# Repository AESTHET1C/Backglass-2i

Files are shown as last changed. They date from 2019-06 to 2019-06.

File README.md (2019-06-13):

# Backglass 2 Integrated Pinball Controller Board

This is the "integrated" version of the [Backglass 2 Pinball Controller Board](https://github.com/AESTHET1C/Backglass-2). The I/O has been changed from wire receptacles to a ribbon cable, and the ordering has changed to better suit wire management.

---

An Arduino Uno-compatible unified control board tailored to the Eli Whitney Museum 2019 summer pinball project.

The board contains the following hardware:

* Microchip ATmega8U2/16U2 (serial communication and code upload)
* Microchip ATmega328P (user code)
* Microchip ATmega48PB (audio/visual coprocessing)
* 4-character 7 segment display
* 2 analogue inputs (for reflectance sensors)
* 5 digital inputs (with integrated pull-ups)
* 3 current-limited LED outputs
* 1 PWM-controlled motor output
* 1 speaker output
* Micro USB interface
* 2.7 - 6.5 volt power input

All features of the board, with the exception of the motor, can be powered via USB.

-----

A user-oriented code library can be found here: <https://github.com/AESTHET1C/Backglass-2-Library/>

The coprocessor firmware can be found here: <https://github.com/AESTHET1C/Backglass-2-Firmware/>

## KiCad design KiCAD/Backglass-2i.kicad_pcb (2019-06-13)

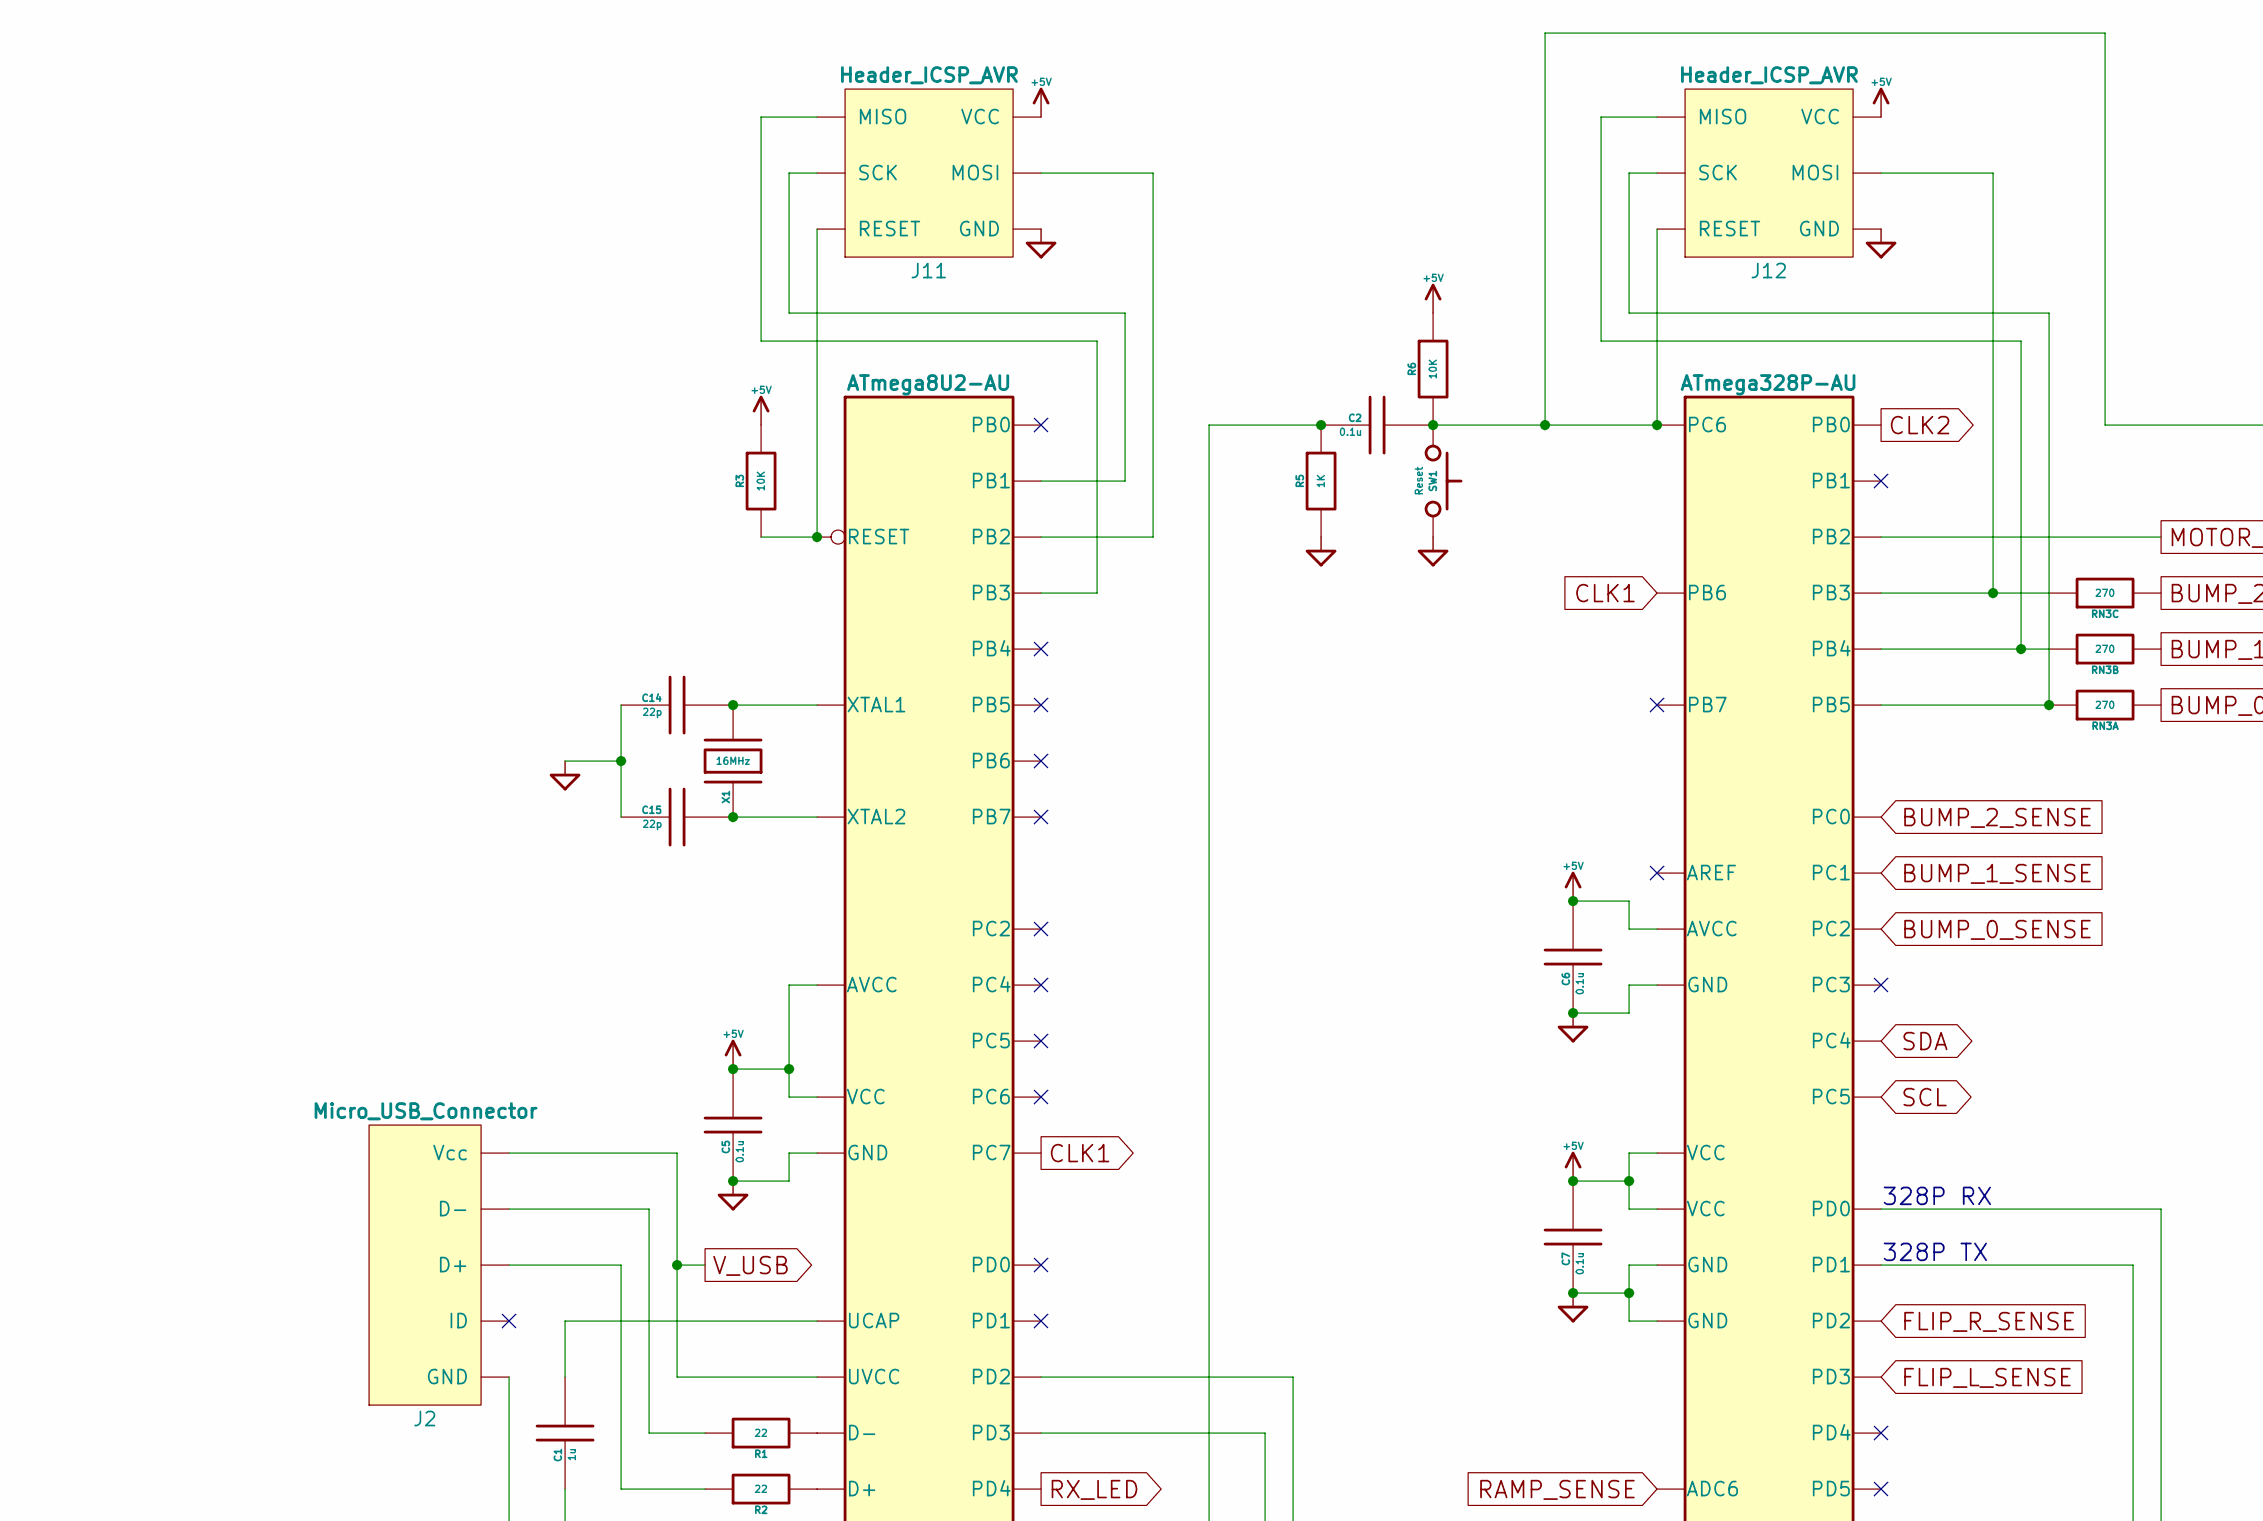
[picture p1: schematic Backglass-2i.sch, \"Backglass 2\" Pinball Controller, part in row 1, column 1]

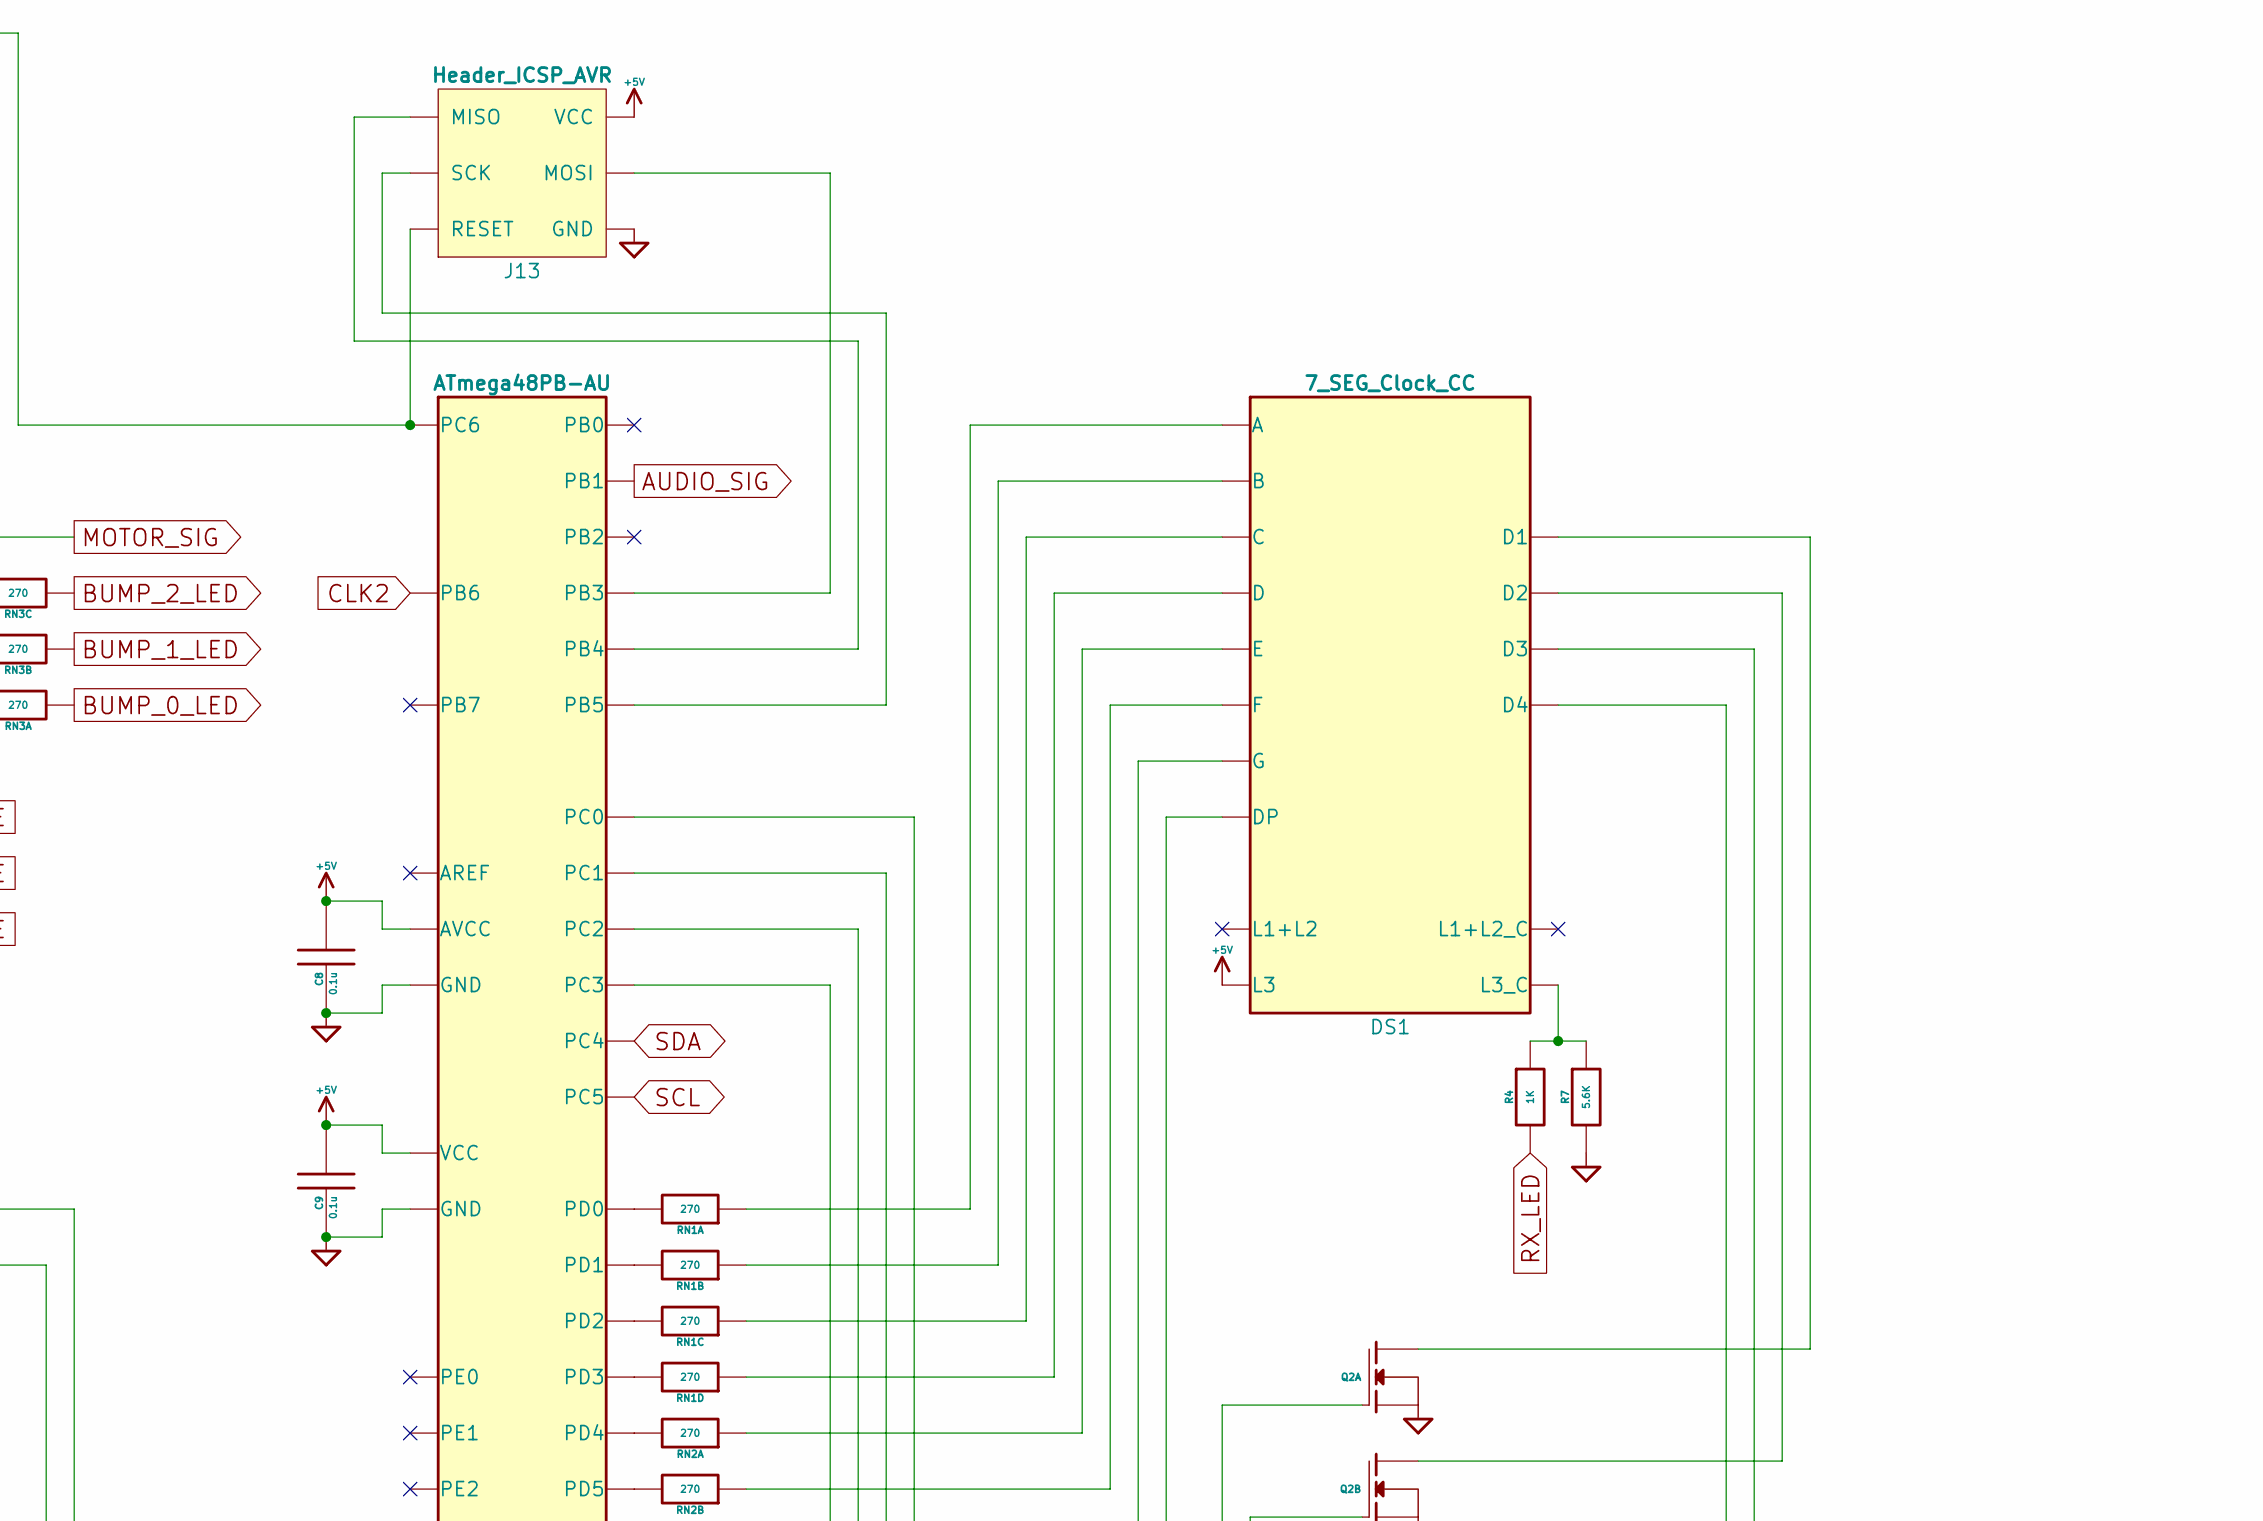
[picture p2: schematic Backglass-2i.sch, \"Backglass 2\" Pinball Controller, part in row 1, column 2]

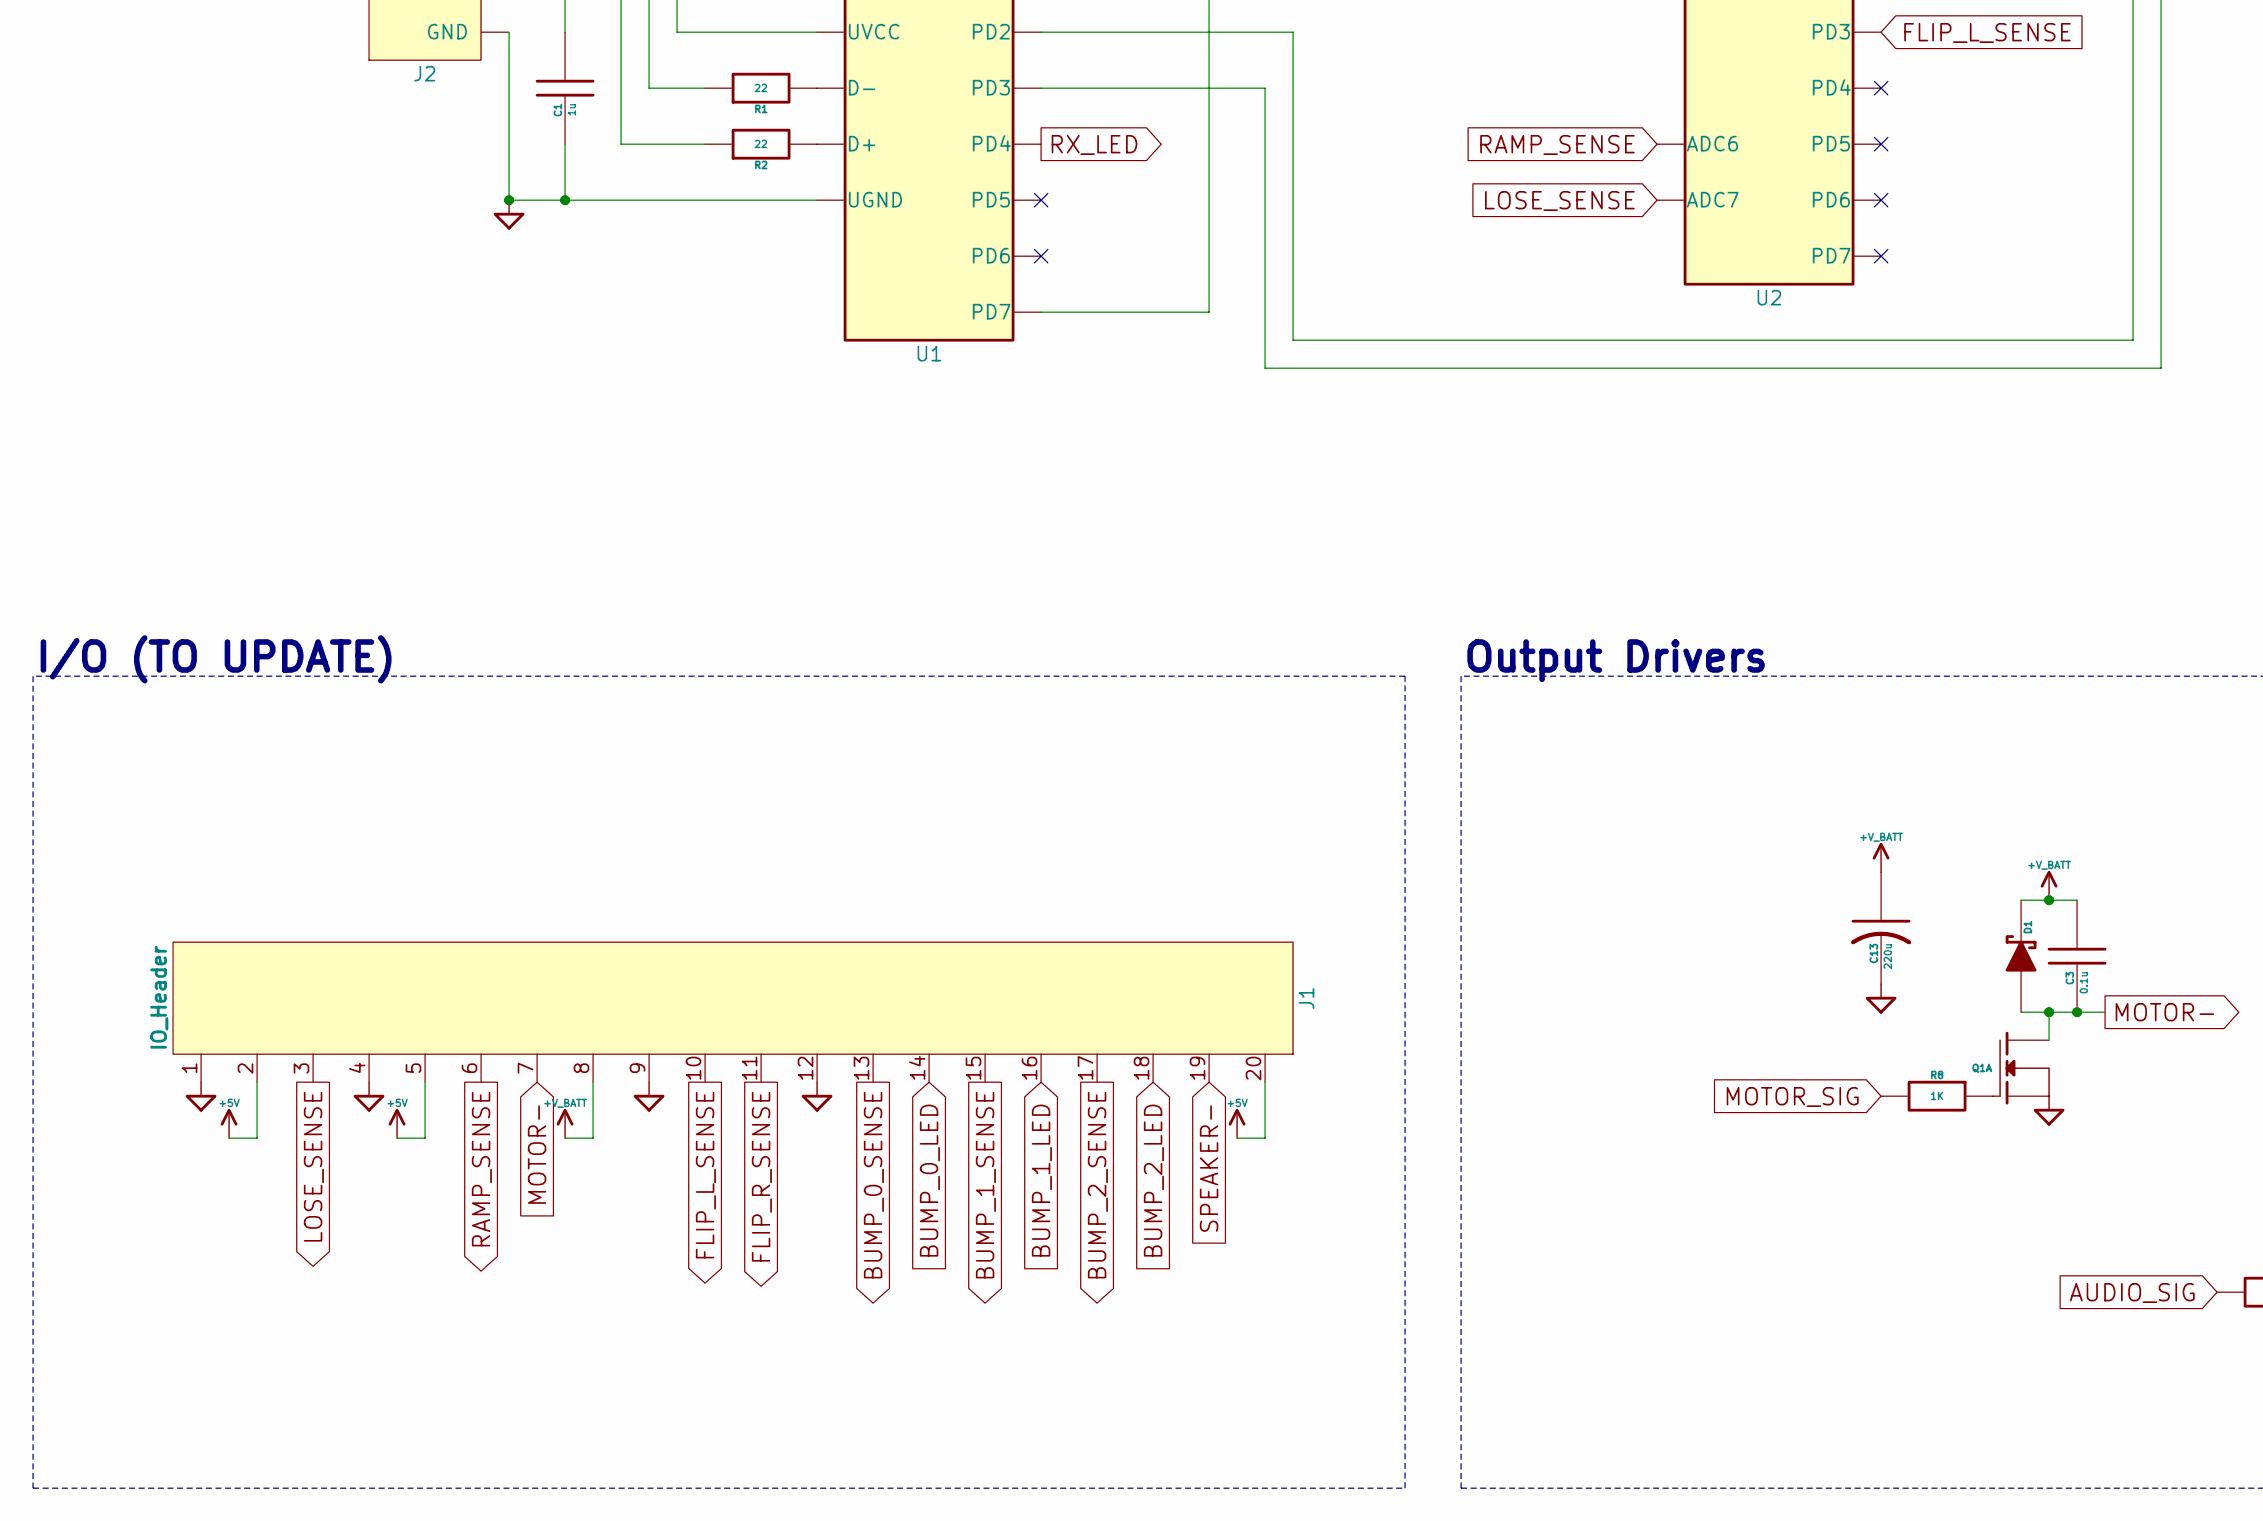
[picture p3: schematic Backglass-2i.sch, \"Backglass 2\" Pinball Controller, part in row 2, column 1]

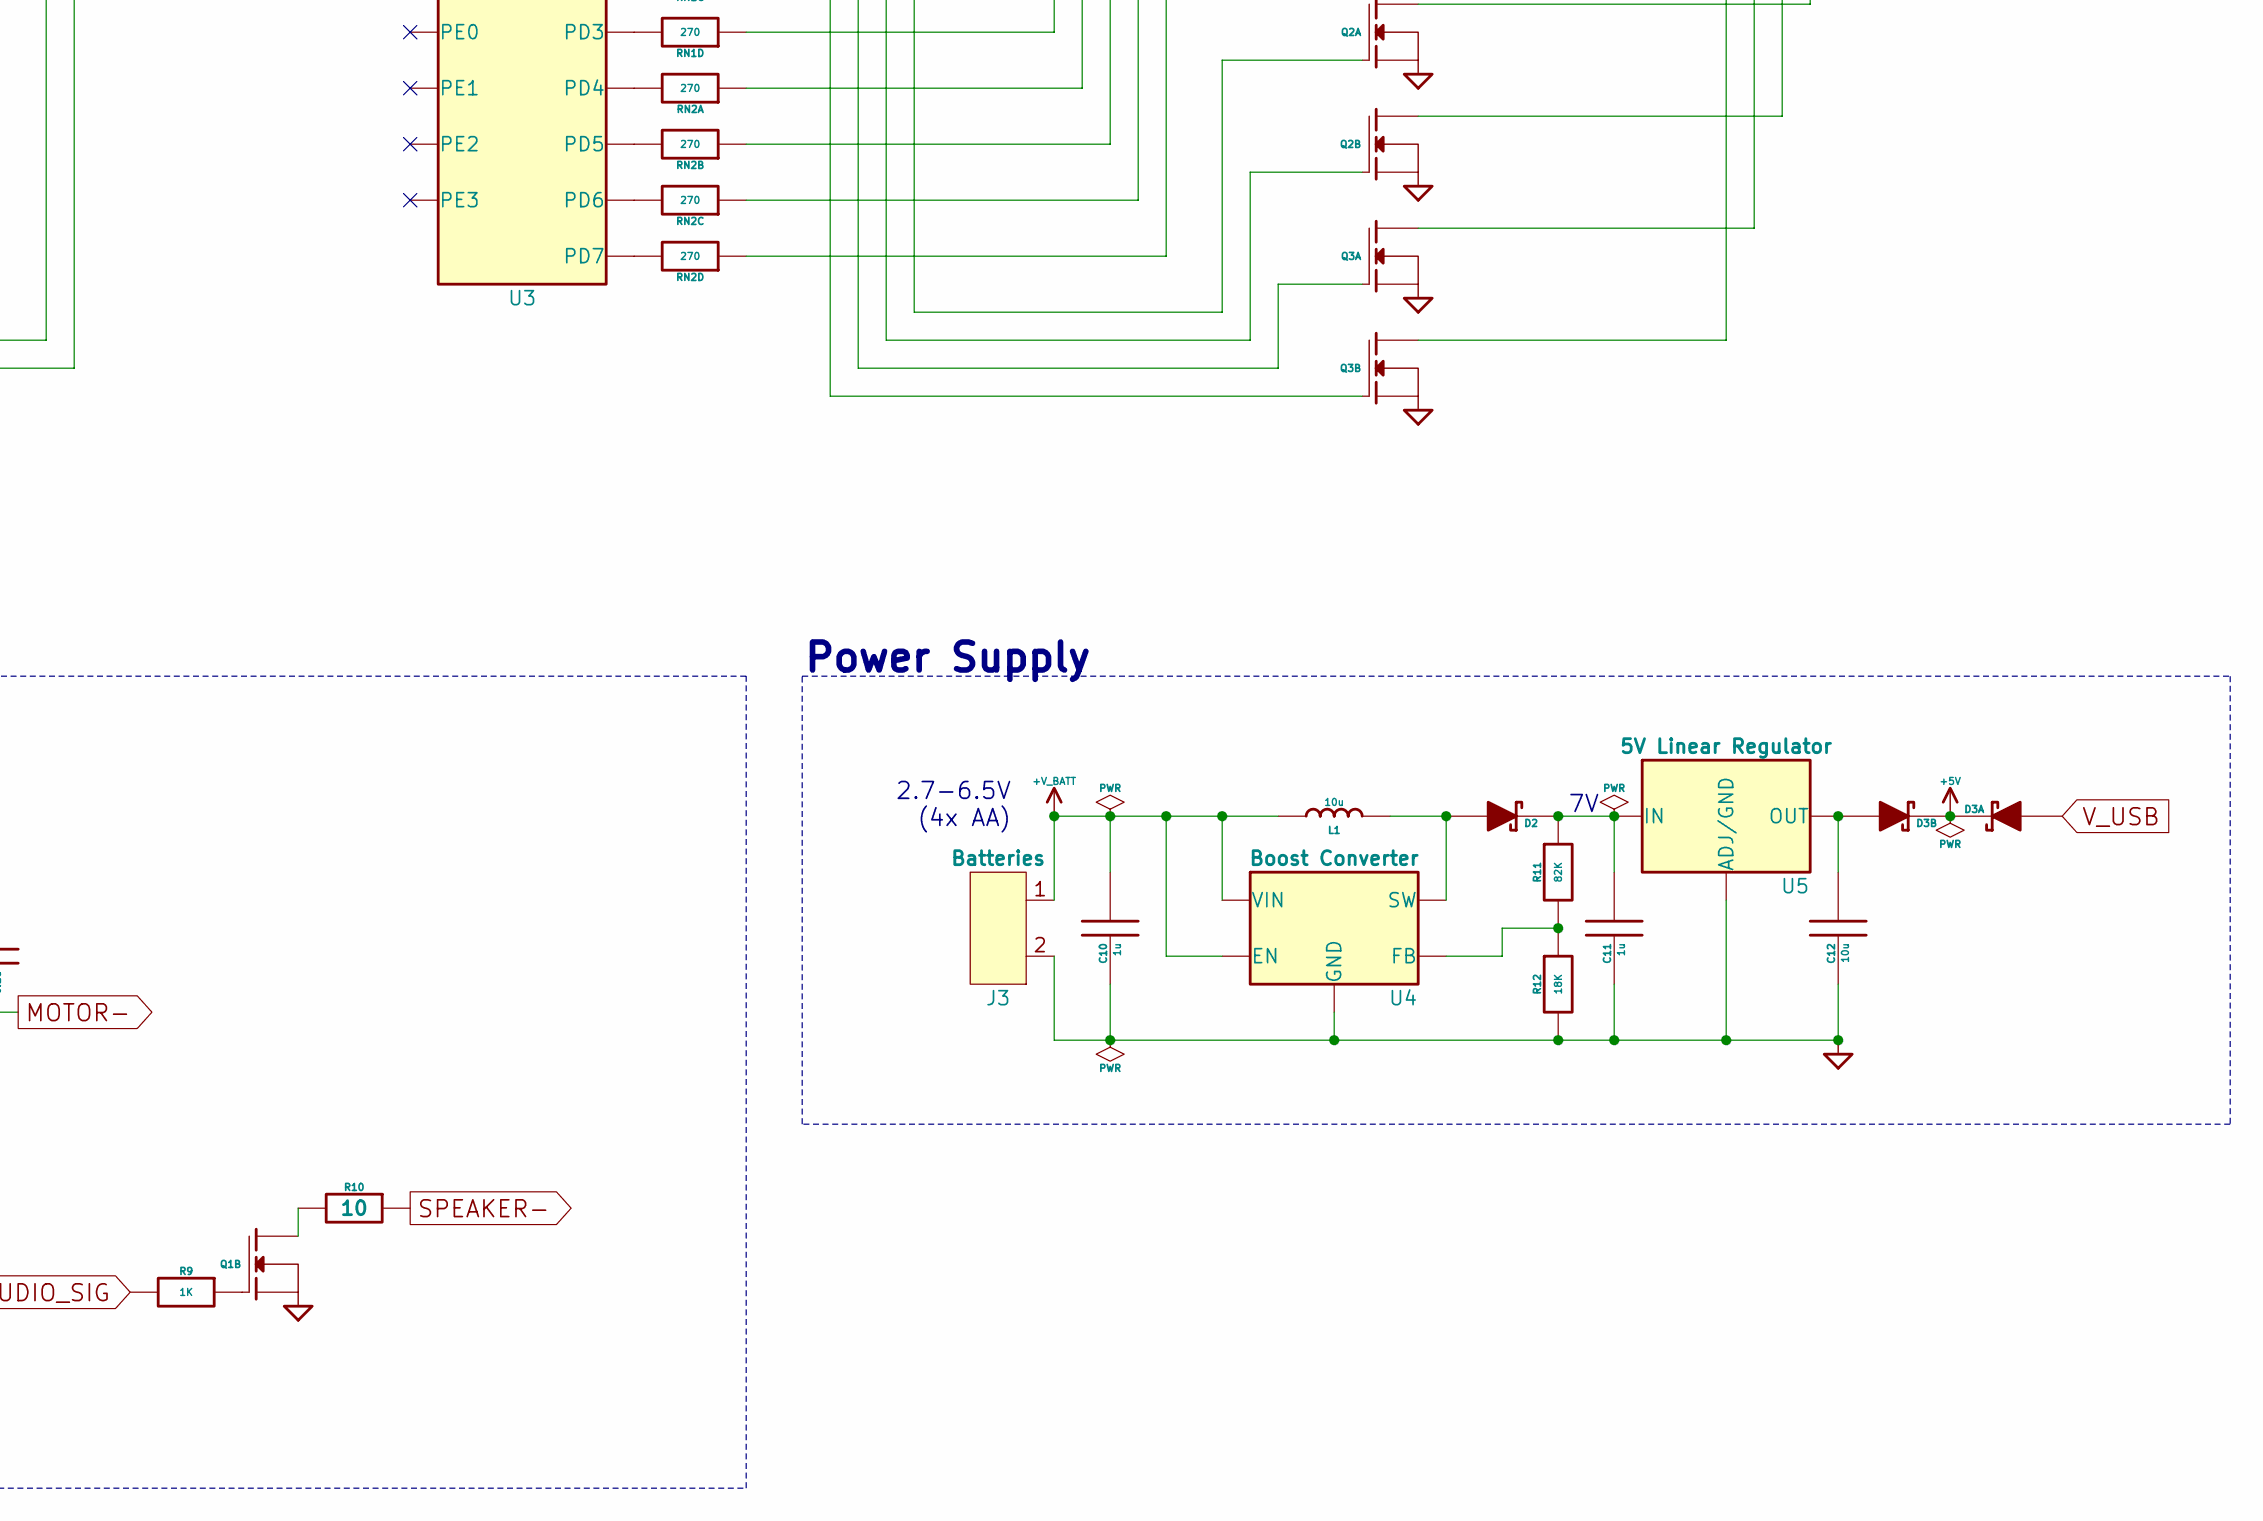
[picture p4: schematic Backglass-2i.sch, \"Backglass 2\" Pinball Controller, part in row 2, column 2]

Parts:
C1, C10, C11: 1u; 1608
C2, C3, C5, C6, C7, C8, C9: 0.1u; 1608
C12: 10u; 2012
C13: 220u; C_6.3-2.5mm
C14, C15: 22p; 1608
D1, D2: D_Schottky; SOT-23-3_A-C
D3: D_Schottky_Dual_CC; SOT-23-3_AAC
DS1: 7_SEG_Clock_CC; TDCx10xxM
J1: IO_Header; TE_1-746610-5
J2: Micro_USB_Connector; Molex_1051640001
J3: Batteries; 2x1_0.1in
J11, J12, J13: Header_ICSP_AVR; AVR_ICSP_0.05in
L1: 10u; 3225
Q1: MOSFET_N_E_Dual; SOT-23-6_G1-S2-G2-D2-S1-D1
Q2, Q3: MOSFET_N_E_Dual; TSSOP-6_S1-G1-D2-S2-G2-D1
R1, R2: 22; 1608
R3, R6: 10K; 1608
R4, R5, R8, R9: 1K; 1608
R7: 5.6K; 1608
R10: 10; 3225
R11: 82K; 1608
R12: 18K; 1608
RN1, RN2, RN3: 270; Array_4x1608_Convex_NP
SW1: Reset; Tact_Switch_6mm
U1: ATmega8U2-AU; TQFP-32
U2: ATmega328P-AU; TQFP-32
U3: ATmega48PB-AU; TQFP-32
U4: Boost Converter; SOT-23-5
U5: 5V Linear Regulator; SOT-223-4
X1: 16MHz; 3.2x2.5_SMD_CRYSTAL

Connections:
+5V: C5.2, C6.2, C7.2, C8.2, C9.2, D3.C, DS1.9 (L3), J1.2, J1.5, J1.20, J11.2 (VCC), J12.2 (VCC), J13.2 (VCC), R3.1, R6.1, U1.4 (VCC), U1.32 (AVCC), U2.4 (VCC), U2.6 (VCC), U2.18 (AVCC), U3.4 (VCC), U3.18 (AVCC)
+V_BATT: C3.2, C10.2, C13.1, D1.C, J1.8, J3.1, L1.1, U4.4 (EN), U4.5 (VIN)
AUDIO_SIG: R9.2, U3.13 (PB1)
BUMP_0_LED: J1.14, RN3.8
BUMP_0_SENSE: J1.13, U2.25 (PC2)
BUMP_1_LED: J1.16, RN3.7
BUMP_1_SENSE: J1.15, U2.24 (PC1)
BUMP_2_LED: J1.18, RN3.6
BUMP_2_SENSE: J1.17, U2.23 (PC0)
CLK1: U1.22 (PC7), U2.7 (PB6)
CLK2: U2.12 (PB0), U3.7 (PB6)
FLIP_L_SENSE: J1.10, U2.1 (PD3)
FLIP_R_SENSE: J1.11, U2.32 (PD2)
GND: C1.1, C5.1, C6.1, C7.1, C8.1, C9.1, C10.1, C11.1, C12.1, C13.2, C14.1, C15.1, J1.1, J1.4, J1.9, J1.12, J2.5 (GND), J3.2, J11.6 (GND), J12.6 (GND), J13.6 (GND), Q1.S1, Q1.S2, Q2.S1, Q2.S2, Q3.S1, Q3.S2, R5.2, R7.2, R12.2, SW1.2 (NO), U1.3 (GND), U1.28 (UGND), U2.3 (GND), U2.5 (GND), U2.21 (GND), U3.5 (GND), U3.21 (GND), U4.2 (GND), U5.1 (ADJ/GND)
LOSE_SENSE: J1.3, U2.22 (ADC7)
MOTOR-: C3.1, D1.A, J1.7, Q1.D1
MOTOR_SIG: R8.2, U2.14 (PB2)
unnamed: C1.2, U1.27 (UCAP)
unnamed: C2.1, R5.1, U1.13 (PD7)
unnamed: C2.2, J12.5 (RESET), J13.5 (RESET), R6.2, SW1.1 (C), U2.29 (PC6), U3.29 (PC6)
unnamed: C11.2, D2.C, R11.1, U5.3 (IN)
unnamed: C12.2, D3.A2, U5.2 (OUT), U5.4
unnamed: C14.2, U1.1 (XTAL1), X1.2
unnamed: C15.2, U1.2 (XTAL2), X1.1
unnamed: D2.A, L1.2, U4.1 (SW)
unnamed: DS1.1 (D1), Q2.D1
unnamed: DS1.2 (D2), Q2.D2
unnamed: DS1.3 (D), RN1.4
unnamed: DS1.5 (E), RN2.1
unnamed: DS1.6 (D3), Q3.D1
unnamed: DS1.7 (DP), RN2.4
unnamed: DS1.8 (D4), Q3.D2
unnamed: DS1.10 (L3_C), R4.1, R7.1
unnamed: DS1.11 (F), RN2.2
unnamed: DS1.13 (C), RN1.3
unnamed: DS1.14 (A), RN1.1
unnamed: DS1.15 (G), RN2.3
unnamed: DS1.16 (B), RN1.2
unnamed: J2.2 (D-), R1.1
unnamed: J2.3 (D+), R2.1
unnamed: J11.1 (MISO), U1.17 (PB3)
unnamed: J11.3 (SCK), U1.15 (PB1)
unnamed: J11.4 (MOSI), U1.16 (PB2)
unnamed: J11.5 (RESET), R3.2, U1.24 (RESET)
unnamed: J12.1 (MISO), RN3.2, U2.16 (PB4)
unnamed: J12.3 (SCK), RN3.1, U2.17 (PB5)
unnamed: J12.4 (MOSI), RN3.3, U2.15 (PB3)
unnamed: J13.1 (MISO), U3.16 (PB4)
unnamed: J13.3 (SCK), U3.17 (PB5)
unnamed: J13.4 (MOSI), U3.15 (PB3)
unnamed: Q1.D2, R10.2
unnamed: Q1.G1, R8.1
unnamed: Q1.G2, R9.1
unnamed: Q2.G1, U3.23 (PC0)
unnamed: Q2.G2, U3.24 (PC1)
unnamed: Q3.G1, U3.25 (PC2)
unnamed: Q3.G2, U3.26 (PC3)
unnamed: R1.2, U1.30 (D-)
unnamed: R2.2, U1.29 (D+)
unnamed: R11.2, R12.1, U4.3 (FB)
unnamed: RN1.5, U3.1 (PD3)
unnamed: RN1.6, U3.32 (PD2)
unnamed: RN1.7, U3.31 (PD1)
unnamed: RN1.8, U3.30 (PD0)
unnamed: RN2.5, U3.11 (PD7)
unnamed: RN2.6, U3.10 (PD6)
unnamed: RN2.7, U3.9 (PD5)
unnamed: RN2.8, U3.2 (PD4)
unnamed: U1.8 (PD2), U2.31 (PD1)
unnamed: U1.9 (PD3), U2.30 (PD0)
RAMP_SENSE: J1.6, U2.19 (ADC6)
RX_LED: R4.2, U1.10 (PD4)
SCL: U2.28 (PC5), U3.28 (PC5)
SDA: U2.27 (PC4), U3.27 (PC4)
SPEAKER-: J1.19, R10.1
V_USB: D3.A1, J2.1 (Vcc), U1.31 (UVCC)

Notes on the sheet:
328P RX
328P TX
2.7-6.5V (4x AA)
Power Supply
I/O (TO UPDATE)
Output Drivers

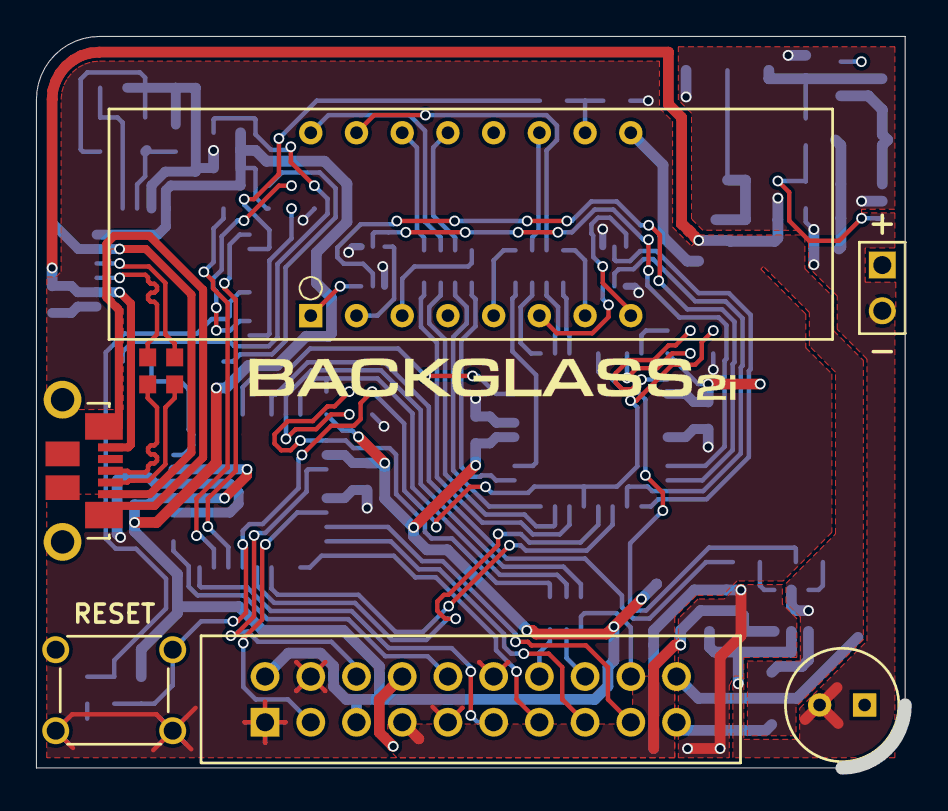
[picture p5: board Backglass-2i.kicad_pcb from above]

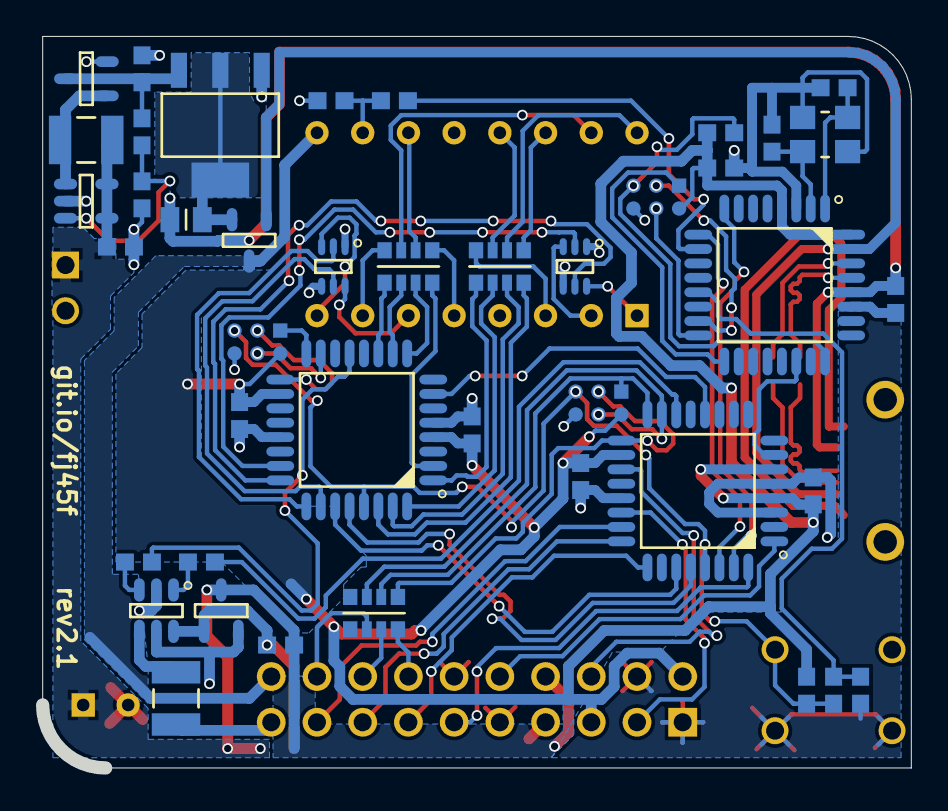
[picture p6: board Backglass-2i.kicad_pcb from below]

Board: 2 copper layers, 48.3 x 40.6 mm, 50 parts (42 on the bottom side), 76 nets.

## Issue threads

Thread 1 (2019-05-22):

ICSP headers may be defective

AESTHET1C, 2019-05-22:
ICSP headers are tented on the front of the board. This may lead to the solder mask filling the vias and not allowing for the pogo pins to seat properly on their pads.

This issue carries over from the Backglass-2 board.

Closed 2019-06-13.

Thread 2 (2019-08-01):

Reflectance sensors report incorrect data if one sensor is connected improperly

AESTHET1C, 2019-08-01:
If a reflectance sensor isn't attached properly (loose connection, etc.), the other sensor returns data for both sensors. The extent of the loose connection (which wire(s)) required for this to happen is currently unknown.

For example, if the RAMP sensor has a loose wire, both the RAMP and LOSE sensors will detect a ball if the LOSE sensor is activated.

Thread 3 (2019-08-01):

Reflectance sensor pinouts reversed

AESTHET1C, 2019-08-01:
The pinouts for the two reflectance sensors are reversed. That is, left-to-right, they are GND, +5V, SIG. However, they should be SIG, +5V, GND.

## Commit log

2019-05-22 Real initial commit
    Copied files over from Backglass-2 repository.
    [Backglass-2i.kicad_pcb, Backglass-2i.sch]
2019-05-22 Minor versioning updates
    Changed Git.io link on silkscreen, updated version of schematic to 2.1, made note of changing I/O section.
    [Backglass-2i.kicad_pcb, Backglass-2i.sch]
2019-06-13 Updated layout
    Changed I/O connector and rerouted traces, removed I/O labels, updated logo
    [Backglass-2i.kicad_pcb, Backglass-2i.sch]
2019-06-13 Updated README
    Changed title and text to reflect the relationship to the Backglass 2 (non-i) board.
2019-06-13 Removed soldermask behind ICSP headers
    [Backglass-2i.kicad_pcb]
